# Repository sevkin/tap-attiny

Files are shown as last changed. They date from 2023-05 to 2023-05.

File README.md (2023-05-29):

# Пьезоконцевик TAP350

Для дельтапринтеров и прочих воронов

* Микроконтроллер attiny13a
* Пьеза 35мм
* Шар 8г (тяжелее 10г может не работать)

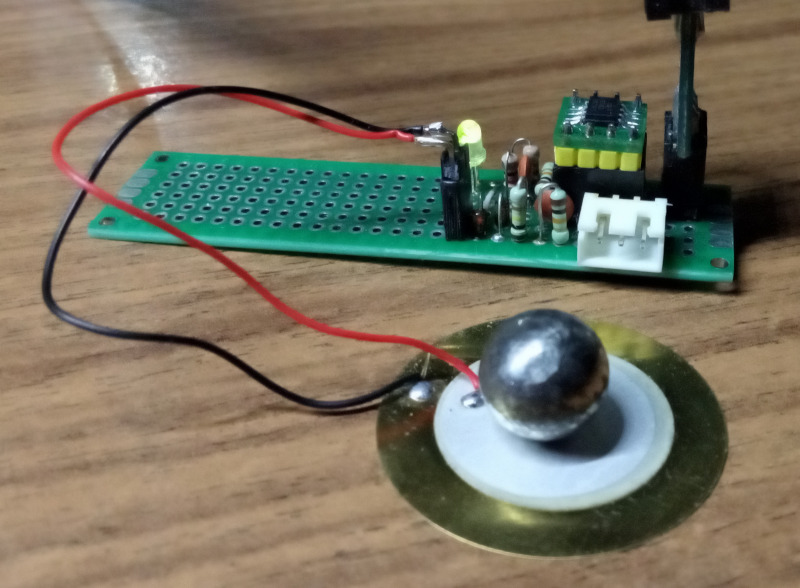
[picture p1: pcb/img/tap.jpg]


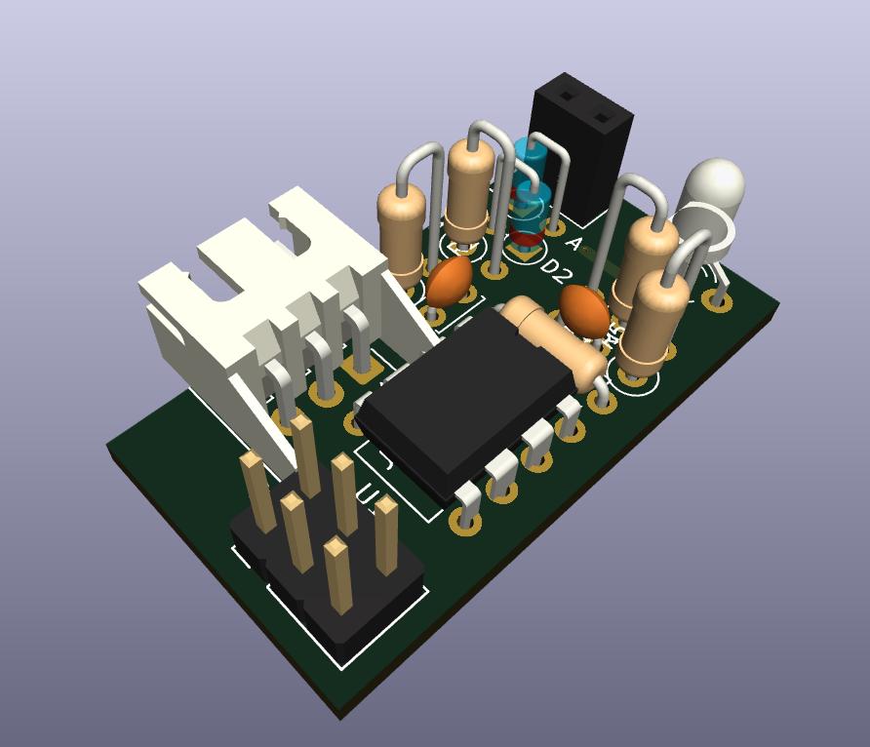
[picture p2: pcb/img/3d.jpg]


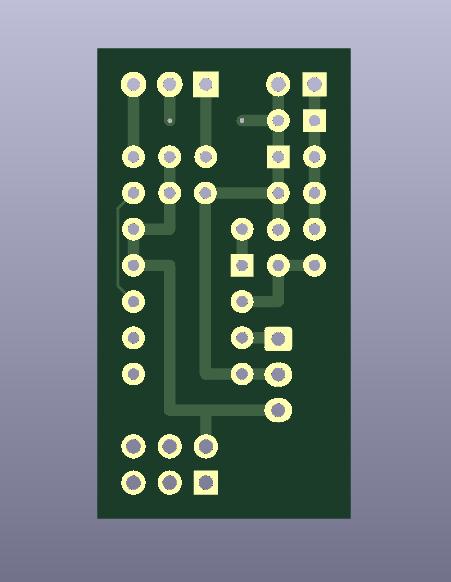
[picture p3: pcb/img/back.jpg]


Прошивочный разъём при*ан на от**бись мгтф проводом.

Основан на схеме и прошивке https://github.com/ripinteer/tap-attiny/

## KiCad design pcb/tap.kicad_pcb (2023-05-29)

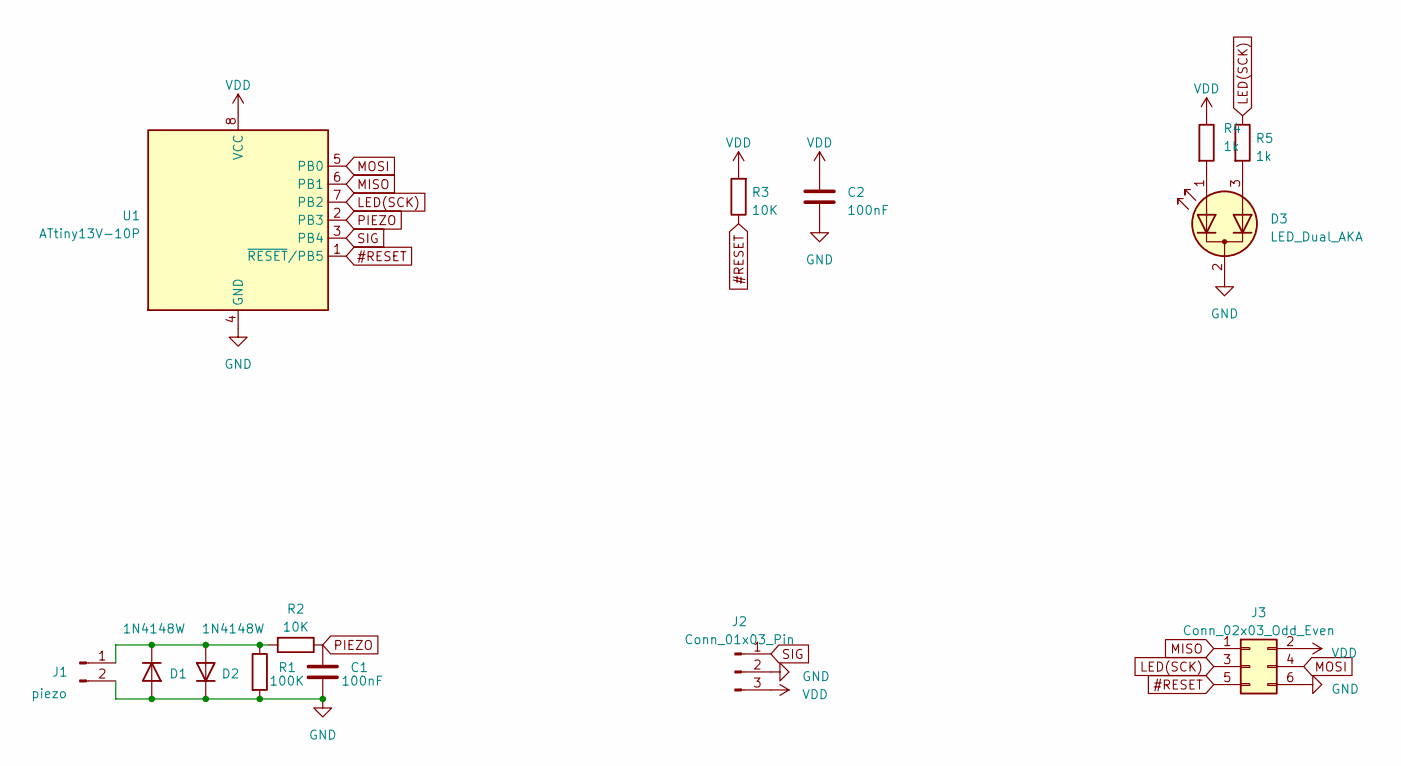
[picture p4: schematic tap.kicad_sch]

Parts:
C1, C2: 100nF; C_Disc_D3.4mm_W2.1mm_P2.50mm
D1, D2: 1N4148W; D_DO-35_SOD27_P2.54mm_Vertical_AnodeUp
D3: LED_Dual_AKA; LED_D3.0mm-3
J1: piezo; PinSocket_1x02_P2.54mm_Vertical
J2: Conn_01x03_Pin; JST_XH_S3B-XH-A-1_1x03_P2.50mm_Horizontal
J3: Conn_02x03_Odd_Even; PinHeader_2x03_P2.54mm_Vertical
R1: 100K; R_Axial_DIN0207_L6.3mm_D2.5mm_P2.54mm_Vertical
R2: 10K; R_Axial_DIN0207_L6.3mm_D2.5mm_P2.54mm_Vertical
R3: 10K; R_Axial_DIN0207_L6.3mm_D2.5mm_P7.62mm_Horizontal
R4, R5: 1k; R_Axial_DIN0207_L6.3mm_D2.5mm_P2.54mm_Vertical
U1: ATtiny13V-10P; DIP-8_W7.62mm

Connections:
#RESET: J3.5, R3.1, U1.1 (~RESET/PB5)
GND: C1.2, C2.2, D1.2 (A), D2.1 (K), D3.2 (K), J1.2, J2.2, J3.6, R1.2, U1.4 (GND)
LED(SCK): J3.3, R5.1, U1.7 (PB2)
MISO: J3.1, U1.6 (PB1)
MOSI: J3.4, U1.5 (PB0)
unnamed: D1.1 (K), D2.2 (A), J1.1, R1.1, R2.2
unnamed: D3.1 (A1), R4.2
unnamed: D3.3 (A2), R5.2
PIEZO: C1.1, R2.1, U1.2 (PB3)
SIG: J2.1, U1.3 (PB4)
VDD: C2.1, J2.3, J3.2, R3.2, R4.1, U1.8 (VCC)

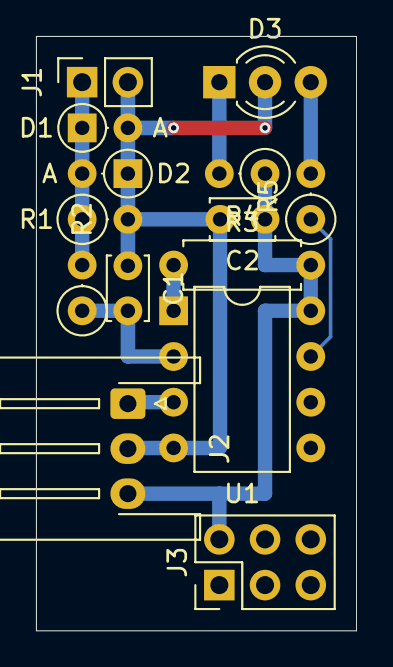
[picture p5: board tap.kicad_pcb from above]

Board: 2 copper layers, 17.8 x 33.0 mm, 14 parts (0 on the bottom side), 11 nets.

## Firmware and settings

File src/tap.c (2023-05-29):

#include <avr/io.h>
#include <util/delay.h>

#define LED PB2
#define OUT PB4
#define DELAY 80
#define SENSIVITY 6

int main() {
  ADMUX = _BV(REFS0) |               // Internal voltage reference
          _BV(ADLAR) |               // 10 bit left ajust result ADCH:ADCL
          _BV(MUX1) | _BV(MUX0);     // ADC3 (PB3)
  ADCSRA |= _BV(ADEN) |              // ADC enable
            _BV(ADPS1) | _BV(ADPS0); // Prescaler 8
  // _BV(ADPS2) | _BV(ADPS1) | _BV(ADPS0); // Prescaler 128

  DDRB |= _BV(LED); // Output for LED indication

  DDRB |= _BV(OUT);  // Output for signal pin for sink
  PORTB &= _BV(OUT); // Disable pull-up

  while (1) {
    ADCSRA |= _BV(ADSC); // Start ADC
    while (ADCSRA & _BV(ADSC))
      ; // Wait for completed

    if (ADCH > SENSIVITY) {

      DDRB &= ~_BV(OUT); // Set up OUT as input (open-drain) for Signal pin
      PORTB |= _BV(LED); // Turn LED on

      _delay_ms(DELAY);

      PORTB &= ~_BV(LED); // Turn LED off
      DDRB |= _BV(OUT);   // Set up OUT as output for (sinking)
    }
  }
}
